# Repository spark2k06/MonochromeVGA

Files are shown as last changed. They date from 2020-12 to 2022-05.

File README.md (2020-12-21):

# Description

MonochromeVGA is a product to enjoy the charm of those monochrome monitors of the time but in the current video systems, and more specifically in your PC monitor. Although it could be connected to any TV, monitor or video system that has VGA inputs.

Select green, amber or B&W as monochromatic color, among others. Change color to monochrome or vice versa easily.

https://hackaday.io/project/166041-monochromevga

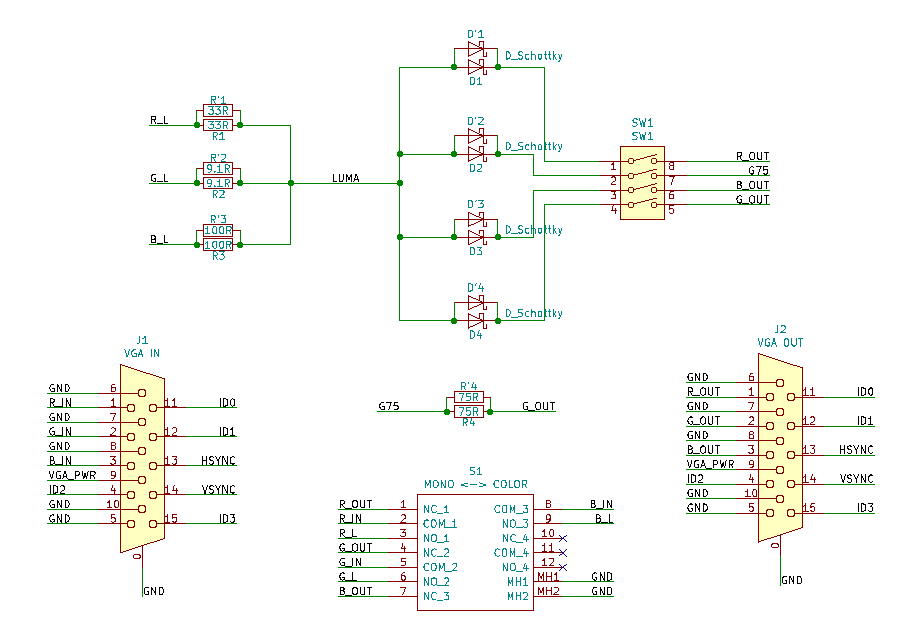
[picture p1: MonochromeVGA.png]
Esquema

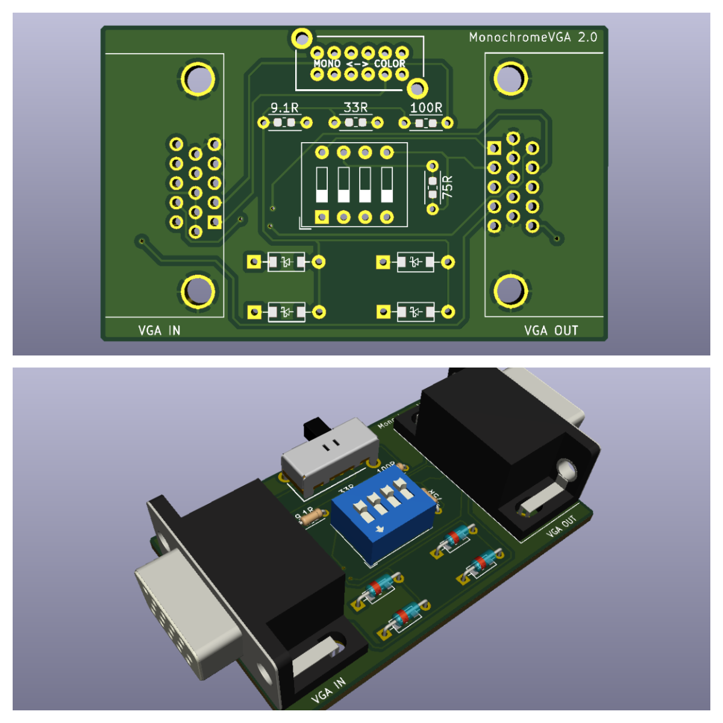
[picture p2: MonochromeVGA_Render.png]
Render


Disclaimer:

It is recommended to use MonochromeVGA inside an shielded container, which can be as simple as a cardboard box lined with aluminium foil, because although unlikely, the VGA signal could interfere with other nearby devices and depending on the laws of your country, it could lead to fines.

In any case, use any hardware posted here at your own risk. 

open hardware facts

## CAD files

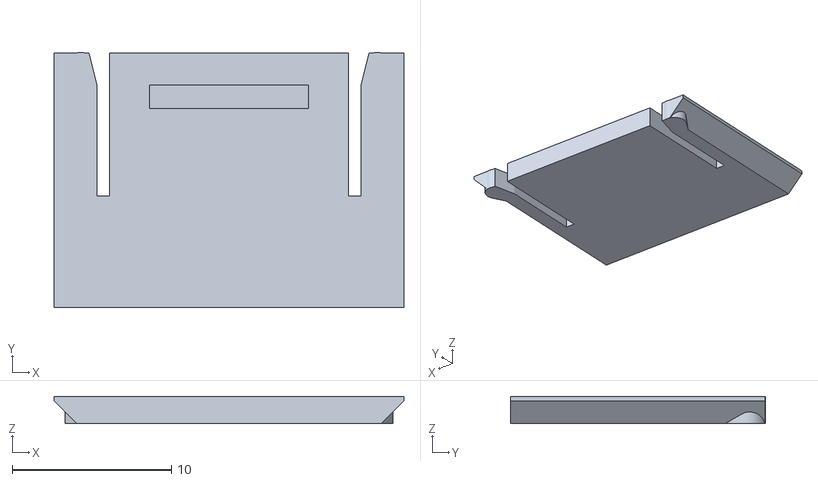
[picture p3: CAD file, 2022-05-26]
3D/Cap.stl
22.0 x 16.0 x 1.70

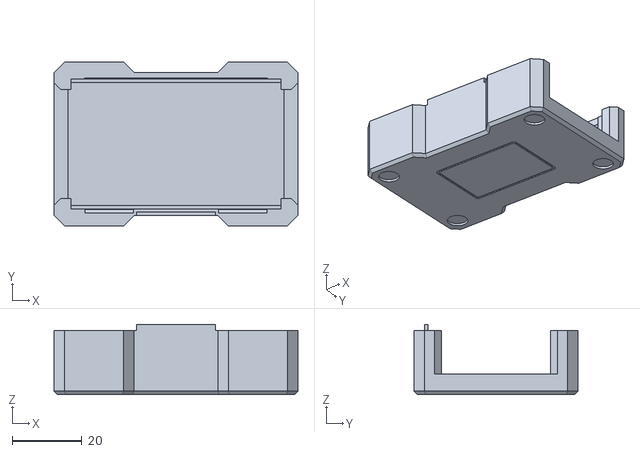
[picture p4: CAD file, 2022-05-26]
3D/Bottom.stl
70.0 x 47.0 x 20.2

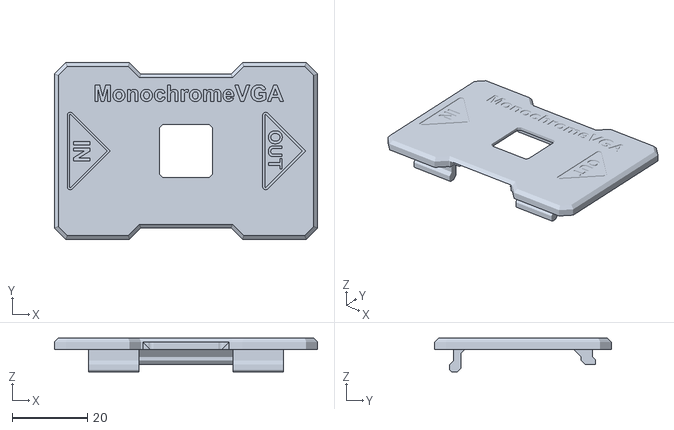
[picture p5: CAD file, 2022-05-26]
3D/Up case.stl
70.0 x 47.0 x 9.00

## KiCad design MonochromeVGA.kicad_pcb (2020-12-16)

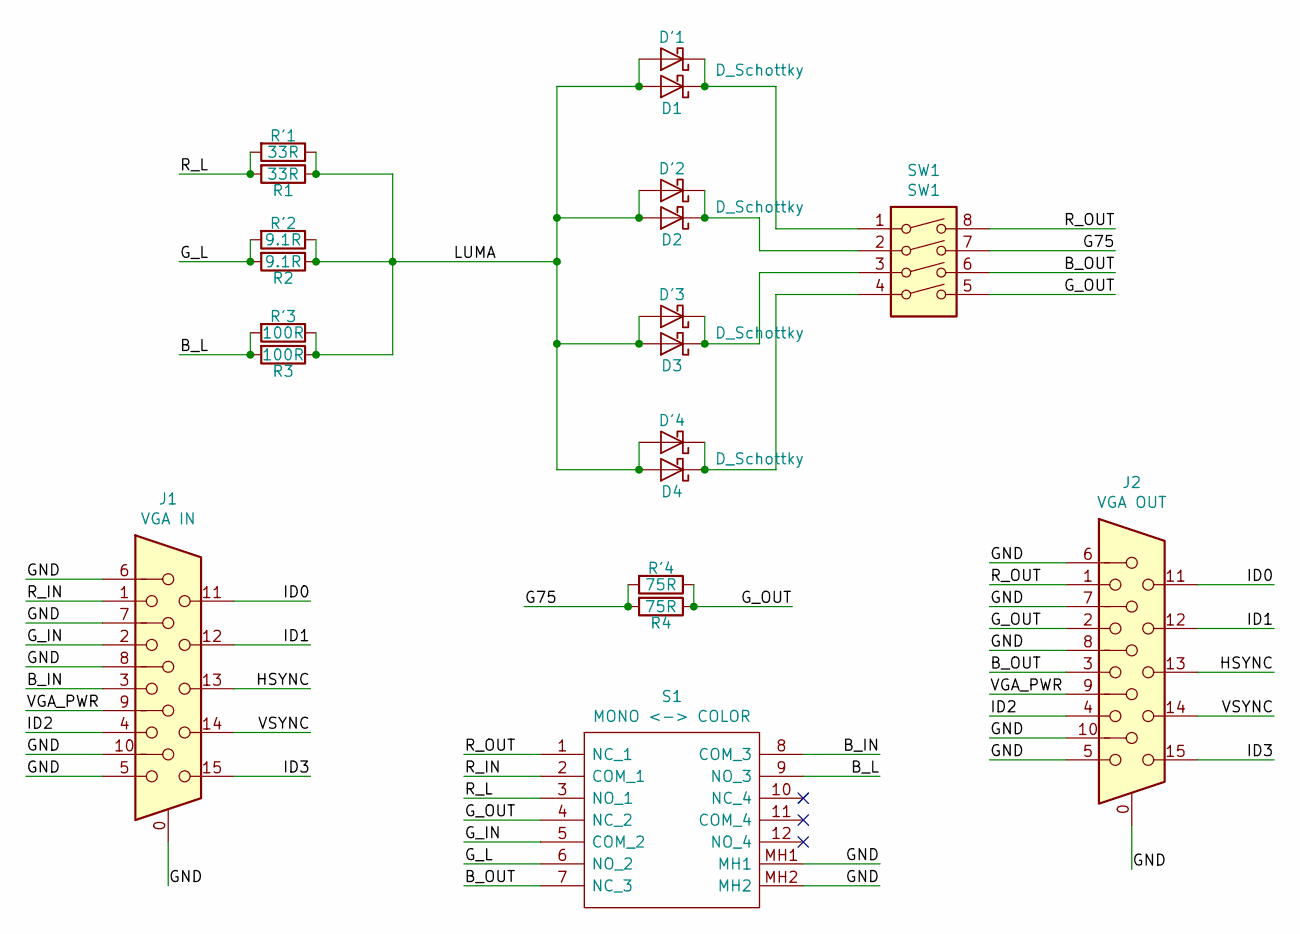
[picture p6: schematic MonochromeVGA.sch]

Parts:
D1, D2, D3, D4: D_Schottky; D_DO-35_SOD27_P7.62mm_Horizontal
D'1, D'2, D'3, D'4: D_SOD-123
J1: VGA IN; DSUB-15-HD_Female_Horizontal_P2.29x1.98mm_EdgePinOffset8.35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
J2: VGA OUT; DSUB-15-HD_Female_Horizontal_P2.29x1.98mm_EdgePinOffset8.35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
R1: 33R; R_Axial_DIN0204_L3.6mm_D1.6mm_P5.08mm_Horizontal
R2: 9.1R; R_Axial_DIN0204_L3.6mm_D1.6mm_P5.08mm_Horizontal
R3: 100R; R_Axial_DIN0204_L3.6mm_D1.6mm_P5.08mm_Horizontal
R4: 75R; R_Axial_DIN0204_L3.6mm_D1.6mm_P5.08mm_Horizontal
R'1: 33R; R_0603_1608Metric
R'2: 9.1R; R_0603_1608Metric
R'3: 100R; R_0603_1608Metric
R'4: 75R; R_0603_1608Metric
S1: MONO <-> COLOR; SW-SK-42D01-G; Mouser Part Number 612-EG4208A
SW1: SW1; SW_DIP_SPSTx04_Slide_9.78x12.34mm_W7.62mm_P2.54mm

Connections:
/B_IN: J1.3, S1.8 (COM_3)
/B_L: R3.2, R'3.2, S1.9 (NO_3)
/B_OUT: J2.3, S1.7 (NC_3), SW1.6
/G75: R4.2, R'4.2, SW1.7
/GND: J1.0, J1.5, J1.6, J1.7, J1.8, J1.10, J2.0, J2.5, J2.6, J2.7, J2.8, J2.10, S1.MH1, S1.MH2
/G_IN: J1.2, S1.5 (COM_2)
/G_L: R2.2, R'2.2, S1.6 (NO_2)
/G_OUT: J2.2, R4.1, R'4.1, S1.4 (NC_2), SW1.5
/HSYNC: J1.13, J2.13
/ID0: J1.11, J2.11
/ID1: J1.12, J2.12
/ID2: J1.4, J2.4
/ID3: J1.15, J2.15
/LUMA: D1.2 (A), D2.2 (A), D3.2 (A), D4.2 (A), D'1.2 (A), D'2.2 (A), D'3.2 (A), D'4.2 (A), R1.1, R2.1, R3.1, R'1.1, R'2.1, R'3.1
/R_IN: J1.1, S1.2 (COM_1)
/R_L: R1.2, R'1.2, S1.3 (NO_1)
/R_OUT: J2.1, S1.1 (NC_1), SW1.8
/VGA_PWR: J1.9, J2.9
/VSYNC: J1.14, J2.14
unnamed: D1.1 (K), D'1.1 (K), SW1.1
unnamed: D2.1 (K), D'2.1 (K), SW1.2
unnamed: D3.1 (K), D'3.1 (K), SW1.3
unnamed: D4.1 (K), D'4.1 (K), SW1.4

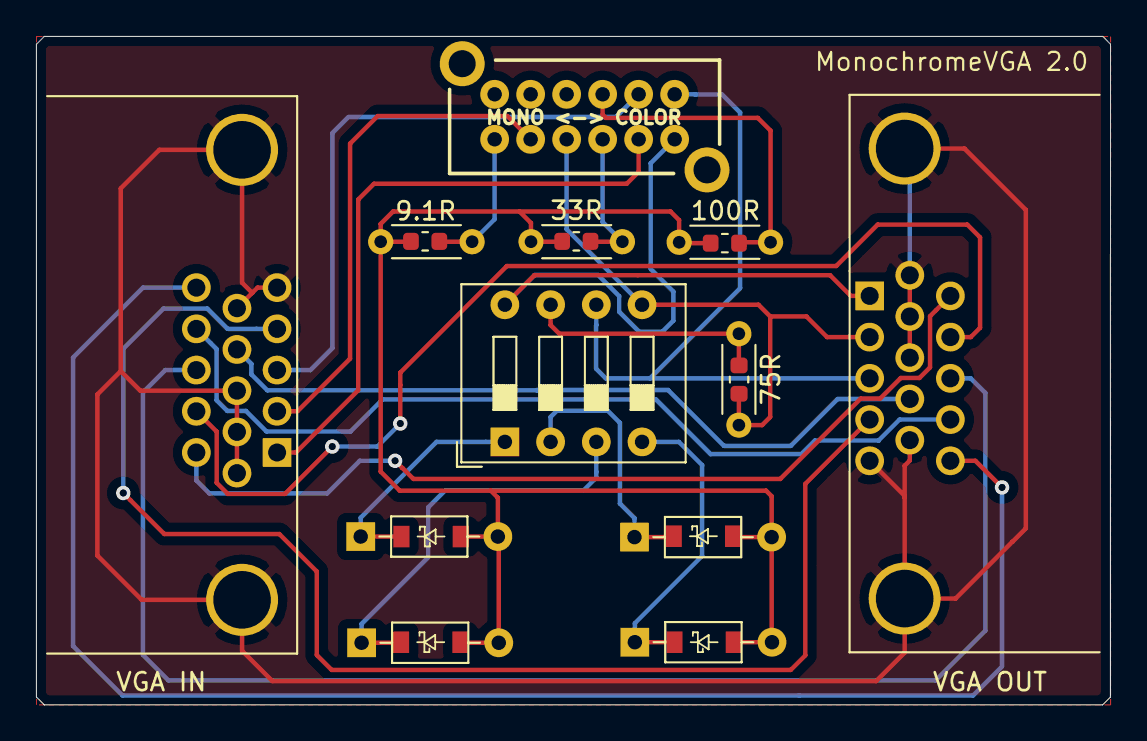
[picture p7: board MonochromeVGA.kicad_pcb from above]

Board: 2 copper layers, 59.7 x 37.1 mm, 20 parts (0 on the bottom side), 23 nets.

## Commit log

2020-12-16 Version 2.0
    Changes from old revision
    The RGB resistors provided are 90% smaller in value, silkscreen indication has been fixed. The filtered output signal is brighter, it can be considered an improvement.
    The VGA input connector is now also female, to prioritize use in a case and more accessible to the user. However, a Mini Gender Changer is also offered, but this time male-male, to connect directly to the video output or to the monitor input, and can be left permanently.
    New PCB design with through hole technology and mixed SMD, for an assembly task adapted to the needs of each one.
    [MonochromeVGA-B_Mask.gbr, MonochromeVGA-B_Paste.gbr, MonochromeVGA-B_SilkS.gbr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]
2022-05-26 3D Case
    [Bottom.stl, Cap.stl, Up case.stl]
